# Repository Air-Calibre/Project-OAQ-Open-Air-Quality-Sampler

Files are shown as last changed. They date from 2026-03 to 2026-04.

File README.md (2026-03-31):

<div align="center">

# Project OAQ
**The Open-Source Air Quality Sampler Made for Everyone.**






OAQ Showcase

*Make AQI measurement cheap, portable, open, and everywhere.*

</div>

---

## The Problem
Air pollution claims approximately 8 million lives every year. Everyone breathing the atmosphere of this planet is affected by it. Yet, the biggest barrier to combating air pollution is a simple lack of localized awareness about its constituents. 

**We want to change that.**

## The Solution: Project OAQ
Project OAQ is a fully open-source, portable, and battery-powered air pollution monitor. It provides real-time AQI values and the exact concentrations of the most influential airborne pollutants. Built for accessibility and actual daily usage.

<div align="center">
  
  
  
</div>

---

## Key Features

- **Ultra-Affordable:** Build it yourself for under $25.
- **Zero SMD Soldering:** 100% Through-hole PCB design makes it the perfect weekend project for beginners.
- **Everyday Carry (EDC):** Designed to look Discrete. It draws less attention, highly portable, powered by a standard rechargeable 18650 Li-ion battery.
- **Privacy First (100% Offline):** No cloud dependency. Connects via Bluetooth Low Energy (BLE) to a local app.
- **Pollution-Aware UX:** Features a built-in buzzer alert system to notify you when air quality reaches dangerous levels.
- **Smart Home Ready:** Easily integrates with Home Assistant for home automation based on air quality triggers.
- **Customizable Enclosure:** 3D printable files included.

---

## Core Technology and Hardware

Our hardware is built around a custom, compact MCU-based PCB measuring just 52mm × 30mm. It utilizes a modular sensor architecture, allowing you to choose the particulate sensor that fits your budget and availability.

<div align="center">
  
  
  
</div>

### Supported Sensors
| Measurement Type | Supported Sensors |
| :--- | :--- |
| **Temperature and Humidity** | `DHT22` |
| **Gas / CO2 / VOC Proxy** | `MQ-135` |
| **Particulate Matter (PM)** | `ZH03`, `PMS5003 / PMS9003`, `SPS30`, `SDS011`, `MPM14`, `ZH06` |

---

## How We Calculate AQI

1. Calculates a sub-index for each detected pollutant.
2. Uses breakpoint-based linear interpolation to standardize values.
3. Applies sensor fusion for enriched context.
4. Determines the Final AQI: Final AQI = max(sub-indices).

<div align="center">
  
  
  
</div>

---

## Software and Ecosystem

### The Firmware
- **Simple and Community-Driven:** Codebase designed for readability.
- **Future Roadmap:** Over-The-Air (OTA) updates and plug-and-play binary support are currently in development.

### The Mobile App
- **BLE Communication:** Fast, low-power pairing.
- **Comprehensive Dashboards:** View AQI alongside raw data from all individual sensors.
- **Local Logging:** Exports data locally as .txt files for your own data science projects.

<div align="center">
  
  
  
</div>

---

## Gallery

<div align="center">
  
  
  
  
  
  
</div>

---

## Contributing
We built this for FOSSHACK 2026, but the mission extends far beyond one event. We welcome pull requests, new sensor integrations, app UI improvements, and 3D enclosure remixes! 

## License
This project is licensed under the **GNU General Public License v3.0**. 

> You are free to copy, modify, and distribute this software, but you must keep all derivative works under the same GPLv3 license and provide the source code. See LICENSE for full details.

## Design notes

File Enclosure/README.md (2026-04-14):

# Project OAQ: 3D Printed Enclosure

This folder contains all the 3D printable files (`.stl` and `.3mf`) required to build the physical enclosure for the **Project OAQ** sampler. The enclosure is designed to be modular, allowing you to swap out internal holders based on the specific particulate matter sensor you are using.

## Printing Instructions

To make an OAQ Sampler of your own, you need to 3D print all the individual common files in this root `Enclosure` folder. Then, based on the particulate matter sensor you are using, 3D print the corresponding holder frame from its respective subfolder.

### Building with the PMS9003 Sensor
If you want to use the **PMS9003 Sensor** within Project OAQ, you will need to print:
1. All the common enclosure files listed below.
2. The specific sensor holder frame found in the `/PMS9003_Holder/` directory.

---

## Directory Structure & Components

The assembly of Project OAQ consists of several key physical components. The files provided map directly to these parts:

### Common Base Files (Required for all builds)
These files remain the exact same regardless of which sensor you choose to install:
* **`FrontCover.3mf`** - The Top Cover of the enclosure.
* **`BackCover.stl`** - The Bottom Cover of the enclosure.
* **`OLED_Spacer.stl`** - Spacer for mounting the display.
* **`Button_Big.stl`** - Button component.
* **`RoundButton_Slit.stl`** - Button component.
* **`SmallButton.stl`** - Button component.

### Sensor-Specific Folders
* **`/PMS9003_Holder/`** - Contains the sensor holder frame specifically for the PMS9003 Particulate Matter Sensor.
* **`/ZH03_Holder/`** - Contains the sensor holder frame for the ZH03 Particulate Matter Sensor.

---

## Assembly Overview

Once you have printed the common files and your chosen sensor holder (e.g., the PMS9003 holder), the full assembly of Project OAQ consists of the following components:

1. **Top Cover** (`FrontCover.3mf`)
2. **Bottom Cover** (`BackCover.stl`)
3. **Buttons** (Using the three button `.stl` files)
   * a. Power Button
   * b. Function Button
   * c. Buzzer Button
4. **Sensor Holder** (From your chosen subfolder, e.g., `/PMS9003_Holder/`)

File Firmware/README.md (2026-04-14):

# Project OAQ: Firmware

This folder contains the Arduino firmware required to operate the **Project OAQ (GoodOne V1)** sampler. Depending on the particulate matter sensor installed in your device, upload the corresponding firmware file to the XIAO ESP32C3 microcontroller.

---

## Available Firmware Versions

- `ZH03_Firmware.ino`  
  Use this if your device is equipped with the ZH03 Particulate Matter Sensor.

- `PMS9003_Firmware.ino`  
  Use this if your device is equipped with the PMS9003 Particulate Matter Sensor.

---

## Core Features

Both firmware versions share the same functionality, differing only in how they parse serial data from their respective particulate sensors.

- **Multi-Screen OLED Display**  
  Displays data across six screens:
  - Main AQI Dashboard  
  - Air Temperature  
  - Relative Humidity  
  - Carbon Monoxide (CO)  
  - PM2.5  
  - PM10  

- **Button Navigation**  
  Interrupt-driven button used to cycle through display screens.

- **BLE Integration**  
  Operates as a Bluetooth Low Energy (BLE) server named `GOOD1-Meter`, broadcasting:
  - Temperature  
  - Humidity  
  - AQI data  

- **Smart AQI Calculation**  
  Computes AQI using both PM2.5 and CO values, selecting the higher value as the final AQI.

- **Audible Alerts**  
  Activates a 1500 Hz buzzer when AQI exceeds 100.

---

## Hardware and Pin Configuration

Ensure the ESP32C3 is wired as follows:

| Component | ESP32C3 Pin | Notes |
|---|---|---|
| I2C OLED SDA | 8 | 128x64 display |
| I2C OLED SCL | 9 | |
| DHT22 Data | 7 | Temperature and humidity |
| Buzzer | 10 | PWM driven |
| Push Button | 3 | Uses `INPUT_PULLUP` |
| PM Sensor RX | 20 | UART (HardwareSerial) |
| PM Sensor TX | 21 | UART (HardwareSerial) |
| Analog CO Sensor | 0 | Analog input (`G1_SENSOR`) |

---

## Dependencies and Libraries

Install the following libraries using the Arduino IDE Library Manager:

- `Wire.h` (built-in)
- `Adafruit_GFX.h` by Adafruit
- `Adafruit_SSD1306.h` by Adafruit
- `DHT sensor library` by Adafruit
- ESP32 BLE libraries:
  - `BLEDevice.h`
  - `BLEServer.h`
  - `BLEUtils.h`
  - `BLE2902.h`  
  (Included with the ESP32 board package)

---

## Flashing Instructions

1. Open the Arduino IDE  
2. Select board: **XIAO ESP32C3**  
3. Open the appropriate firmware file:
   - `ZH03_Firmware.ino` or  
   - `PMS9003_Firmware.ino`  
4. Connect the XIAO ESP32C3 via USB  
5. Select the correct COM port  
6. Click **Upload**

---

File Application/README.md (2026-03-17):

## Prerequisites

Ensure the following are installed before running the project:

- Node.js
- npm / yarn / pnpm
- Java Development Kit (JDK) 17
- Android Studio with Android SDK
- Expo CLI (`npm install -g expo`)
- Git

For Android development:
- Android emulator with Bluetooth support or a physical Android device with USB debugging enabled through developer options after enabling them by clicking build number ~7 times on your phone.

> This project uses Expo Dev Client (not Expo Go).
> You still need Expo Go installed on your Phone.

Installation & Running

1) Clone the repository

```cmd
git clone https://github.com/Air-Calibre/App-dev.git
cd App-dev
```

2) Install dependencies:

```cmd
npm install
```

3) Ensure an Android device or emulator is connected:

```cmd
adb devices
```

You should see your device displayed here. If it says UNAUTHORIZED make sure USB debugging is on and when you get the prompt to allow your PC to access your device allow it.

4) Prebuild native projects:
```cmd
npx expo prebuild
```

5) Build and run the app on Android:

```cmd
npx expo run:android
```

6) Choose android:
```cmd
a
```

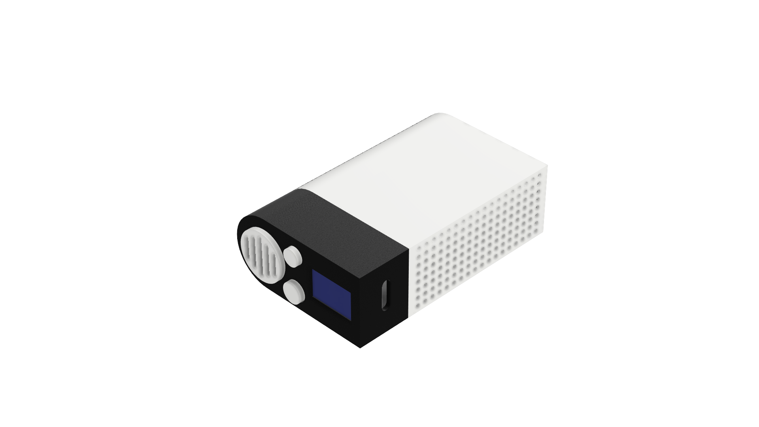
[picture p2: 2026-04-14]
Media/Renders/Render (9).png

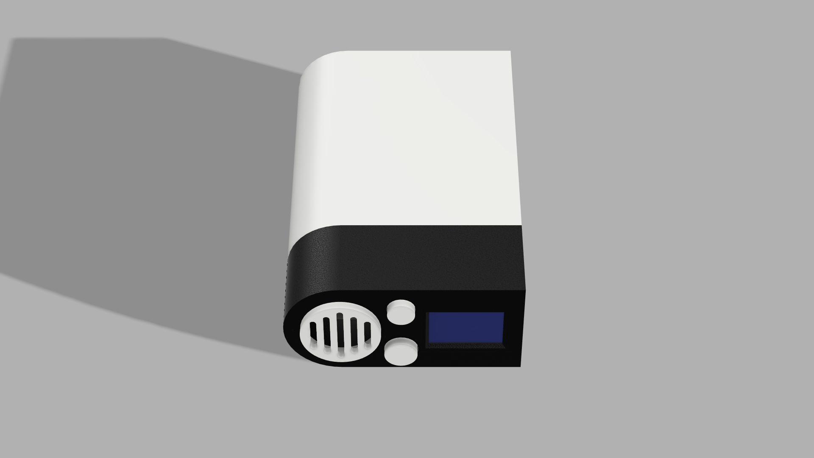
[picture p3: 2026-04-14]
Media/Renders/Render (19).png

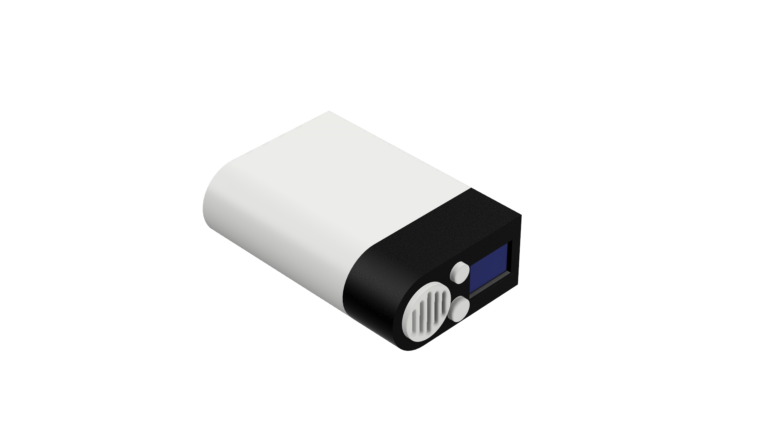
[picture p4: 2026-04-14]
Media/Renders/Render (8).png

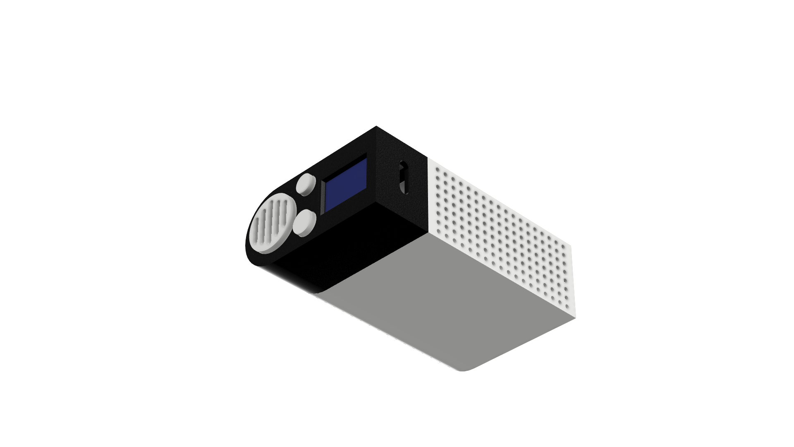
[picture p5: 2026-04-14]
Media/Renders/Render (6).png

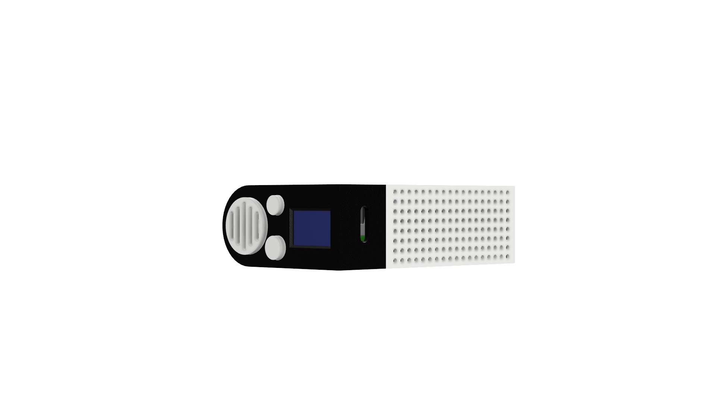
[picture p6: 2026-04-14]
Media/Renders/Render (10).png

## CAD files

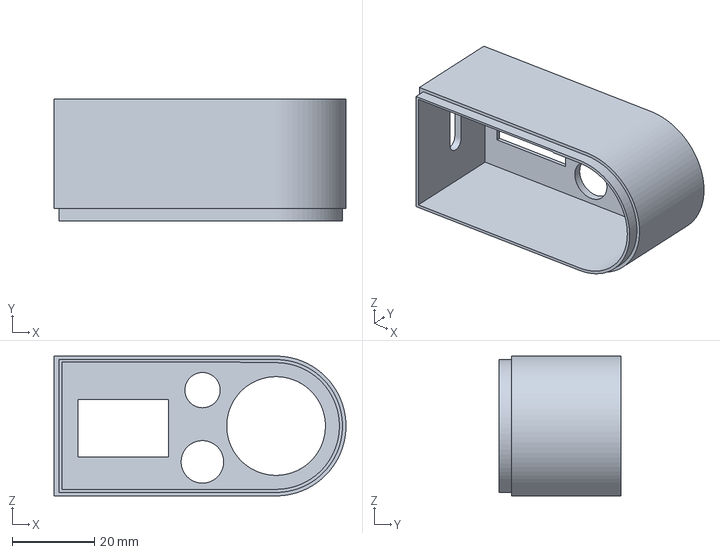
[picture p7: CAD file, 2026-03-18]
Enclosure/FrontCover.3mf
71.0 x 29.6 x 34.0 mm

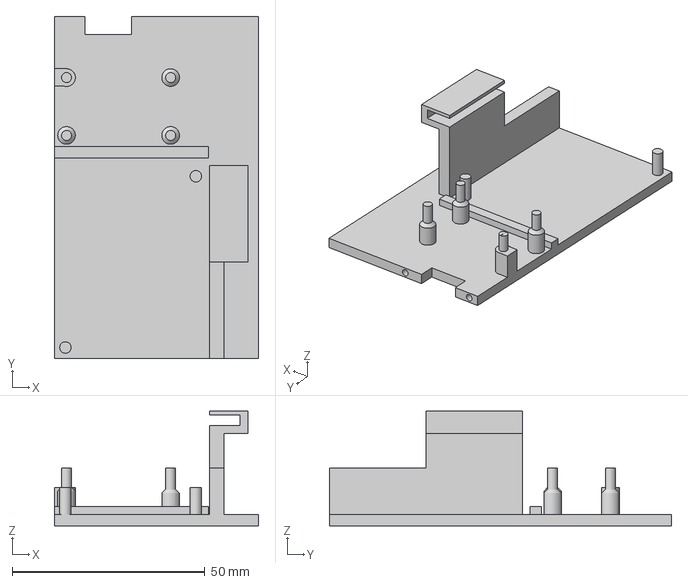
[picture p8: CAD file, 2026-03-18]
Enclosure/PMS9003_Holder/PMS9003_Holder.3mf
53.0 x 88.7 x 29.8 mm

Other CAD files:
Enclosure/ZH03_Holder/ZH03_Holder.3mf

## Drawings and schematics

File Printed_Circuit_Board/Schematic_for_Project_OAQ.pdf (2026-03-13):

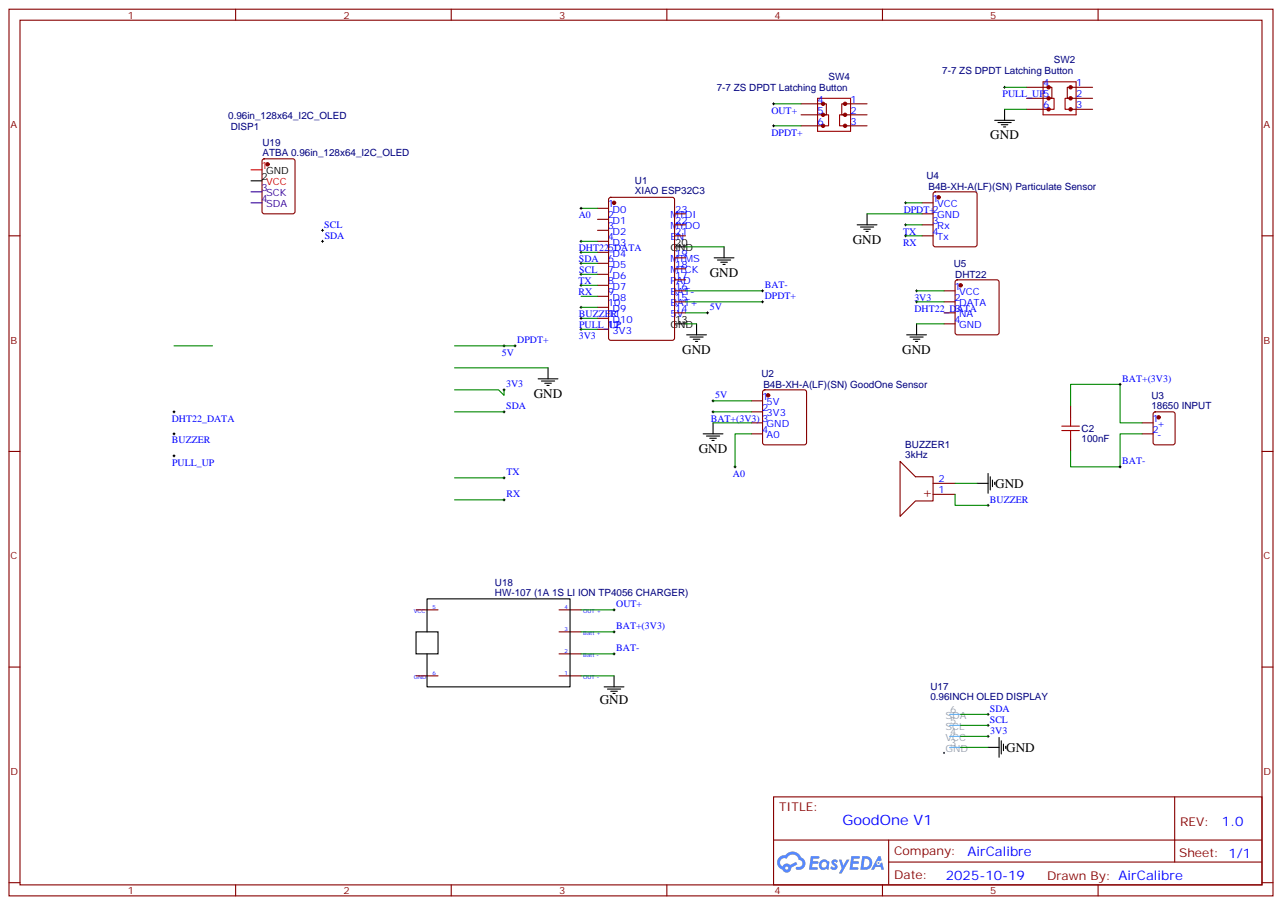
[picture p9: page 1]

7-7 ZS DPDT Latching Button

HW-107 (1A 1S LI ION TP4056 CHARGER)

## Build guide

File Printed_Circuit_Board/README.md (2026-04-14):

# Project OAQ: GoodOne V1 PCB





This repository contains the printed circuit board (PCB) design files, documentation, and manufacturing files for **Project OAQ**, officially titled **GoodOne V1**. Designed by **AirCalibre**, this board is built for environmental and air quality monitoring applications.

---

## Hardware Overview

The GoodOne V1 PCB integrates a microcontroller, multiple environmental sensors, an OLED display, and a rechargeable battery system.

### Core Components

- **Microcontroller:** XIAO ESP32C3 (U1)  
- **Display:** 0.96" 128x64 I2C OLED (U17 / U19 / DISP1)  
- **Audio Output:** BUZZER 3kHz (BUZZER1)  
- **Capacitor:** 100nF (C2)  

### Sensors

- **Temperature & Humidity:** DHT22 (U5)  
- **Particulate Sensor:** B4B-XH-A(LF)(SN) Particulate Sensor (U4)  
- **Secondary Sensor:** B4B-XH-A(LF)(SN) GoodOne Sensor (U2)  

### Power System

- **Battery:** 18650 cell (U3)  
- **Charger Module:** HW-107 (1A 1S Li-Ion TP4056 Charger) (U18)  
- **Power Switches:** SW2 and SW4 7-7 ZS DPDT Latching Buttons  

---

## 🔌 Wiring & Pin Definitions

### I2C Display (OLED)

- **SDA:** Connected to the SDA pin on the ESP32C3 and the OLED display  
- **SCL:** Connected to the SCL pin on the ESP32C3 and the OLED display  
- **Power:** Powered via 3V3 and GND lines  

### Sensors

- **DHT22:** Utilizes the DATA line for communication  
- **Particulate Sensor:** Uses serial communication over TX and RX pins  

### Power Distribution

- **Charging:** The TP4056 charger manages the 18650 battery via BAT+ and BAT- terminals  
- **System Voltage:** Distributes 5V and 3V3 power lines with common GND  
- **Switching:** DPDT switches control power flow across the circuit  

---

## Manufacturing & Fabrication Files

This repository includes industry-standard Gerber and Excellon drill files for direct submission to PCB fabrication houses.  
All files were generated using EasyEDA v6.5.54 on **2026-03-13**.

### Drill Files (.DRL)

- **Drill_NPTH_Through.DRL** – Non-plated through holes  
- **Drill_PTH_Through_Via.DRL** – Plated through vias  
- **Drill_PTH_Through.DRL** – Standard plated through holes  

### Gerber Files

- **Gerber_BoardOutlineLayer.GKO** – Board outline and dimensions  
- **Gerber_TopLayer.GTL** – Top copper traces  
- **Gerber_BottomLayer.GBL** – Bottom copper traces  
- **Gerber_BottomSolderMaskLayer.GBS** – Bottom solder mask  
- **Gerber_BottomSilkscreenLayer.GBO** – Bottom silkscreen  
- **Gerber_BottomPasteMaskLayer.GBP** – Bottom paste mask  
- **Gerber_DocumentLayer.GDL** – Additional documentation layer  

---

## Getting Started

1. Clone this repository to your local machine  
2. Open the project in EasyEDA or import Gerber files into a CAM viewer    
3. Submit `.DRL` and `.G*` files to a PCB manufacturer (e.g., JLCPCB, PCBWay)  

---

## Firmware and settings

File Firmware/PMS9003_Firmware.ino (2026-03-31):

#include <Wire.h>
#include <Adafruit_GFX.h>
#include <Adafruit_SSD1306.h>
#include "DHT.h"
#include <BLEDevice.h>
#include <BLEServer.h>
#include <BLEUtils.h>
#include <BLE2902.h>
#include <math.h> 

// -------------------- PINS & CONFIG --------------------
#define SDAPIN 8
#define SCKPIN 9
#define DHTPIN 7
#define DHTTYPE DHT22
#define BUZZER_PIN 10
#define BUTTON_PIN 3
#define RX_PIN 20
#define TX_PIN 21
#define G1_SENSOR 0

#define RL_VALUE 10.0      
#define R0_CLEAN_AIR 4.5   

#define SCREEN_WIDTH 128
#define SCREEN_HEIGHT 64
Adafruit_SSD1306 display(SCREEN_WIDTH, SCREEN_HEIGHT, &Wire, -1);

// -------------------- GLOBALS -------------------------
DHT dht(DHTPIN, DHTTYPE);
HardwareSerial zhSerial(1);
BLECharacteristic *pCharacteristic;

float temperature = 0, humidity = 0, pm25 = 0, pm10 = 0, aqi = 0, co = 0;
uint8_t screenIndex = 0;
volatile bool buttonPressed = false;
volatile unsigned long lastISRTime = 0;
bool deviceConnected = false;

// -------------------- BLE CALLBACKS --------------------
class MyServerCallbacks : public BLEServerCallbacks {
  void onConnect(BLEServer* pServer) { deviceConnected = true; }
  void onDisconnect(BLEServer* pServer) { 
    deviceConnected = false; 
    BLEDevice::startAdvertising(); 
  }
};

void IRAM_ATTR handleButton() {
  unsigned long now = millis();
  if (now - lastISRTime > 250) {
    buttonPressed = true;
    lastISRTime = now;
  }
}

// -------------------- SENSOR MATH ---------------------
void calculateCO() {
  int rawADC = analogRead(G1_SENSOR);
  float volt = (rawADC / 4095.0) * 3.3;
  if (volt < 0.1) { co = 0; return; }
  float rs = ((3.3 * RL_VALUE) / volt) - RL_VALUE;
  float ratio = rs / R0_CLEAN_AIR;
  co = 599.48 * pow(ratio, -1.512); 
}

void readPMS9003() {
  static uint8_t buf[32];
  static uint8_t idx = 0;

  while (zhSerial.available()) {
    uint8_t b = zhSerial.read();

    if (idx == 0 && b != 0x42) continue;
    if (idx == 1 && b != 0x4D) { idx = 0; continue; }

    buf[idx++] = b;

    if (idx >= 32) {
      idx = 0;

      // PMS9003 standard atmospheric values
      pm25 = (float)((buf[12] << 8) | buf[13]);
      pm10 = (float)((buf[14] << 8) | buf[15]);

      // Optional extra data if needed
      // float pm1 = (buf[10] << 8) | buf[11];
    }
  }
}

void drawProProgressBar(int currentAqi) {
  int barW = 26; int barH = 5; int gap = 4; int y = 52;
  int levels = 0;
  if (currentAqi > 0)   levels = 1;
  if (currentAqi > 50)  levels = 2;
  if (currentAqi > 100) levels = 3;
  if (currentAqi > 150) levels = 4;

  for (int i = 0; i < 4; i++) {
    int x = 6 + (i * (barW + gap));
    if (i < levels) display.fillRect(x, y, barW, barH, WHITE);
    else display.drawRect(x, y, barW, barH, WHITE);
  }
}

void displayValues() {
  display.clearDisplay();
  display.setTextSize(1);
  display.setCursor(0, 0);
  display.print("GOOD1");

  String status = (aqi <= 50) ? "EXCELLENT" : (aqi <= 100) ? "MODERATE" : (aqi <= 150) ? "POOR" : "CRITICAL";
  int16_t sx1, sy1; uint16_t sw, sh;
  display.getTextBounds(status, 0, 0, &sx1, &sy1, &sw, &sh);
  display.setCursor(SCREEN_WIDTH - sw, 0);
  display.print(status);
  display.drawFastHLine(0, 10, 128, WHITE);

  display.setTextSize(3);
  String aStr = String((int)aqi);
  int16_t x1, y1; uint16_t w, h;
  display.getTextBounds(aStr, 0, 0, &x1, &y1, &w, &h);
  display.setCursor((SCREEN_WIDTH - w) / 2, 18); 
  display.print(aStr);

  display.setTextSize(1);
  display.setCursor(56, 42); display.print("AQI");
  drawProProgressBar((int)aqi);
  display.display();
}

void showDetail(String label, float val, String unit) {
  display.clearDisplay();
  display.setTextSize(1);
  display.setCursor(0, 0); display.print(label);
  display.drawFastHLine(0, 10, 128, WHITE);
  display.setTextSize(3);
  String vStr = String(val, (val > 99 ? 0 : 1));
  int16_t x1, y1; uint16_t w, h;
  display.getTextBounds(vStr, 0, 0, &x1, &y1, &w, &h);
  display.setCursor((128-w)/2, 25);
  display.print(vStr);
  display.setTextSize(1);
  display.setCursor(128 - (unit.length() * 6), 55);
  display.print(unit);
  display.display();
}

void setup() {
  Serial.begin(115200);
  dht.begin();
  zhSerial.begin(9600, SERIAL_8N1, RX_PIN, TX_PIN);
  ledcAttach(BUZZER_PIN, 2000, 8); 
  
  pinMode(BUTTON_PIN, INPUT_PULLUP);
  attachInterrupt(digitalPinToInterrupt(BUTTON_PIN), handleButton, FALLING);

  Wire.begin(SDAPIN, SCKPIN);
  display.begin(SSD1306_SWITCHCAPVCC, 0x3C);
  display.setTextColor(WHITE);

  BLEDevice::init("GOOD1-Meter");
  BLEServer *pServer = BLEDevice::createServer();
  pServer->setCallbacks(new MyServerCallbacks());
  BLEService *pService = pServer->createService("4fafc201-1fb5-459e-8fcc-c5c9c331914b");
  pCharacteristic = pService->createCharacteristic("beb5483e-36e1-4688-b7f5-ea07361b26a8", BLECharacteristic::PROPERTY_NOTIFY);
  pCharacteristic->addDescriptor(new BLE2902());
  pService->start();
  pServer->getAdvertising()->start();
}

void loop() {
  readPMS9003();
  
  static unsigned long lastSensorRead = 0;
  if (millis() - lastSensorRead > 2000) {
    temperature = dht.readTemperature();
    humidity = dht.readHumidity();
    calculateCO();
    
    // Weighted AQI logic
    float a_pm = (pm25 / 35.0) * 100.0;
    float a_co = (co / 9.0) * 100.0;
    aqi = max(a_pm, a_co);
    
    if (deviceConnected) {
      String data = String(temperature) + "," + String(humidity) + "," + String(aqi);
      pCharacteristic->setValue(data.c_str());
      pCharacteristic->notify();
    }
    lastSensorRead = millis();
  }

  if (buttonPressed) {
    screenIndex = (screenIndex + 1) % 6;
    buttonPressed = false;
  }

  switch (screenIndex) {
    case 0: displayValues(); break;
    case 1: showDetail("AIR TEMPERATURE", temperature, "C"); break;
    case 2: showDetail("RELATIVE HUMIDITY", humidity, "%"); break;
    case 3: showDetail("CARBON MONOXIDE", co, "PPM"); break;
    case 4: showDetail("PM 2.5", pm25, "ug/m3"); break;
    case 5: showDetail("PM 10", pm10, "ug/m3"); break;
  }
  
  if (aqi > 100 && (millis() % 5000 < 100)) {
     ledcWriteTone(BUZZER_PIN, 1500); delay(50); ledcWriteTone(BUZZER_PIN, 0);
  }
}

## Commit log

2026-04-13 Add README documentation for GoodOne V1 PCB
    Added detailed documentation for Project OAQ: GoodOne V1 PCB, including hardware overview, wiring definitions, and manufacturing files.
2026-04-13 Enhance README with printing and assembly instructions
    Expanded README with detailed printing instructions and assembly overview for Project OAQ, including sensor-specific requirements.

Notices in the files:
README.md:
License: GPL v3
